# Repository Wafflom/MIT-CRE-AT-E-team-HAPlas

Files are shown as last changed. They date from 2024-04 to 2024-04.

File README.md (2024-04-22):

# MIT-CRE[AT]E-team-HAPlas
Code and CAD models repository for our MIT CRE[AT]E challenge device, a haptic and auditory feedback device.

# BOM:
### Electronics:
  - [Seeed Studio XIAO nRF52840 Sense](https://www.seeedstudio.com/Seeed-XIAO-BLE-Sense-nRF52840-p-5253.html)
  - [DFPlayer mini MP3 player](https://www.dfrobot.com/product-1121.html)
  - [1W 40mm 2 pin speaker](https://www.amazon.com/Fielect-Magnet-Speaker-Internal-Loudspeaker/dp/B083TDLGNB?th=1)
  - [UltraFire 10440 Li-ion battery](https://www.batteryupgrade.com/shopBrowser.php?assortmentProductId=21883872&shopGroupId=70741364)
  - Sacrificial USB-C Cable (it will be cut to hijack the power pins, so use one you do not need anymore)
### Hardware:
  - 4x M3x8mm Countersunk hex head screws
  - 1.5mm thick, 15mm wide double-sided foam tape
  - 26AWG wire (for the electronics)
  - 250~ grams of PLA (PLA+ recommended, color is up to preference) We used [Bambulabs PLA MATTE](https://us.store.bambulab.com/products/pla-matte-filament?variant=41078280093832)
  - 12mm Brass rod (other types of dense metal can be used depending on preference and availiability)

### Tools:
  - Soldering Iron
  - 3d Printer
  - Screwdriver
  - Lathe

# Printed Parts and settings
[STL's found here](https://github.com/Wafflom/MIT-CREATE-team-HAPlas/tree/002e4f92e56438b101ec2bbca2ead18dcc9f6623/STL's)
## Main Body STL
#### QTY: 1
### Suggested Print Settings:
  - 0.16mm Layer Height
  - 3 Walls
  - 6 Top & Bottom layers
  - 20% Infill
  - Cubic infill pattern
  - Supports on (tree supports suggested)

#### Orientation in slicer (Orca slicer shown)

#### Sliced with Supports (Orca slicer shown)


## Electronics Bay Cap STL
#### QTY: 1
### Suggested Print Settings:
  - 0.2mm Layer Height
  - 3 Walls
  - 100% Infill
  - Supports off

#### Orientation in slicer (Orca slicer shown)

#### Sliced No Supports


## Cap STL
#### QTY: 2
### Suggested Print Settings:
  - 0.16mm Layer Height
  - 3 Walls
  - 4 Top & Bottom layers
  - 40% infill
  - Cubic infill pattern
  - Supports off

#### Orientation in slicer (Orca slicer shown)

#### Sliced No Supports (Orca slicer shown)


## Battery Holder STL
#### QTY: 1
### Suggested Print Settings:
  - 0.16mm Layer Height
  - 3 Walls
  - 100% Infill
  - Supports on (tree supports suggested)

#### Orientation in slicer (Orca slicer shown)

#### Sliced with Supports (Orca slicer shown)


# Code upload instructions
## Install the Arduino IDE 
  - [Download link](https://www.arduino.cc/en/software)
## Install the Seeed Studio board library
  - After opening the Arduino IDE click on File > Preference, and fill in Additional Boards Manager URLs with the URL below:
    https://files.seeedstudio.com/arduino/package_seeeduino_boards_index.json

## Select which program variant you want to use
  - [click here for code options](https://github.com/Wafflom/MIT-CREATE-team-HAPlas/tree/86a4da8f8bbf2c63ec49366ca752f0183104cafe/Code)
## Select the board in Arduino programmer and hit upload


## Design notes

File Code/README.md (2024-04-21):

# Code used for audio playback
Two different variants of the program have been provided. The first, `Code_Simple.ino` is a simple one that activates the audio upon exceeding an acceleration threshold (measured in m/s^2) that can be used by users desiring a more simple device that always activates sound on the action. The second program, `Code_Gesture_detection.ino`, the one used in our final product and testing footage, utilizes a gesture recognition machine learning model made using edge impulse. This option allows users to correspond specific sounds to specific actions that can be made; we have provided the one we used for our final iteration if you would like to try it out without having to create your own model. ``Note that this model was calibrated for the movements of a 5-year-old and may not function well for an adult.``
# Using Gesture recognition:
### If the usage of gesture recognition is desired, you can either use the included gesture library:
  - [Gesture Library](https://github.com/Wafflom/MIT-CRE-AT-E-team-HAPlas/tree/48943a845ded3df958085c8eb5ed810e9c71b0dc/Code/Gesture%20Library)
### Or you can create your own using these instructions provided by Seedduino:
  - [Library creation instructions](https://wiki.seeedstudio.com/XIAOEI/)
    
## Default Gestures:
  - Jab (straight punch)
  - Uppercut
  - Hook
## Library upload instructions:
  - Download the library

  - Upload to Arduino IDE

  - Include the library in the program

  **Note If using your own library, replace the file name in the quotations with your own library name
    
# File naming convention:
`*Note this is only if you want to use your own audio, if you want to use the same ones we did you can find those files here:` [Audio We Used](https://github.com/Wafflom/MIT-CREATE-team-HAPlas/tree/86a4da8f8bbf2c63ec49366ca752f0183104cafe/Code/Audio%20Files)
#### When uploading audio files to the SD card for the MP3 player, ensure that the files are in the root directory of the SD card and are named 001, 002, 003... etc. 
#### You will call to play these files using the function:
```ruby
myDFPlayer.play(/*number*/);
```
#### With the number corresponding to the file you want to be played, this convention for naming should also be used if the user desires to use different audio files than the ones we used.

# Code upload instructions
## Install the Arduino IDE 
  - [Download link](https://www.arduino.cc/en/software)
## Install the Seeed Studio board library
  - After opening the Arduino IDE click on File > Preference, and fill in Additional Boards Manager URLs with the URL below:
    https://files.seeedstudio.com/arduino/package_seeeduino_boards_index.json

## Select the board in Arduino programmer and hit upload


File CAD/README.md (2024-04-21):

# Files made in Fusion 360 on education license
### Revisions denoted by the final number in the file name, Revision 1 being first and 3 being the latest and final variant
  - .STEP and .F3d/.F3z files all provided

# BOM:
### Electronics:
  - [Seeed Studio XIAO nRF52840 Sense](https://www.seeedstudio.com/Seeed-XIAO-BLE-Sense-nRF52840-p-5253.html)
  - [DFPlayer mini MP3 player](https://www.dfrobot.com/product-1121.html)
  - [1W 40mm 2 pin speaker](https://www.amazon.com/Fielect-Magnet-Speaker-Internal-Loudspeaker/dp/B083TDLGNB?th=1)
  - [UltraFire 10440 Li-ion battery](https://www.batteryupgrade.com/shopBrowser.php?assortmentProductId=21883872&shopGroupId=70741364)
  - Sacrificial USB-C Cable (it will be cut to hijack the power pins, so use one you do not need anymore)
### Hardware:
  - 4x M3x8mm Countersunk hex head screws
  - 1.5mm thick, 15mm wide double-sided foam tape
  - 26AWG wire (for the electronics)
  - 250~ grams of PLA (PLA+ recommended, color is up to preference) We used [Bambulabs PLA MATTE](https://us.store.bambulab.com/products/pla-matte-filament?variant=41078280093832)

### Tools:
  - Soldering Iron
  - 3d Printer
  - Screwdriver

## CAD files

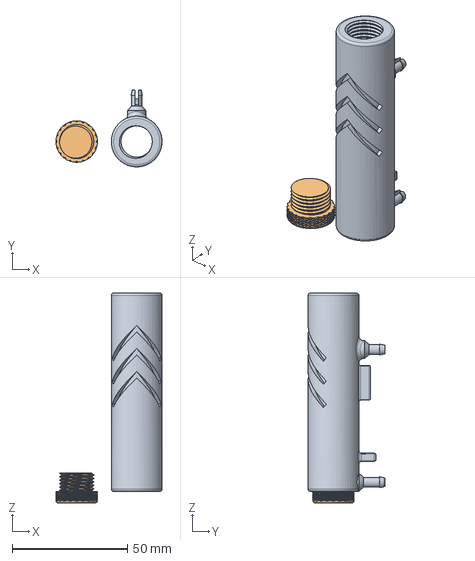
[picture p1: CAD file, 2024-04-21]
CAD/Haptic Attachment Full CAD STEP Revision 2.step
46.0 x 33.3 x 91.0 mm

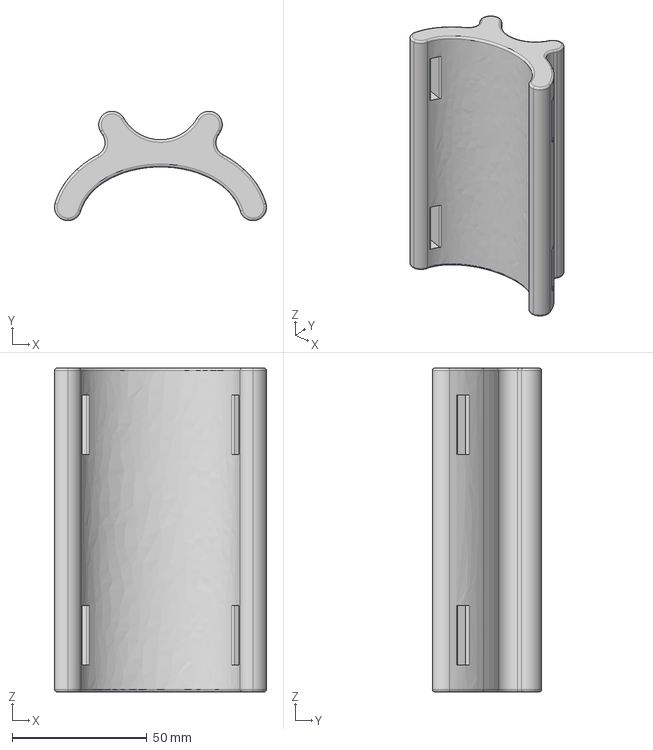
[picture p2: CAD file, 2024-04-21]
CAD/Prototype arm mount Full CAD STEP Revision 1.step
78.6 x 40.5 x 120.0 mm

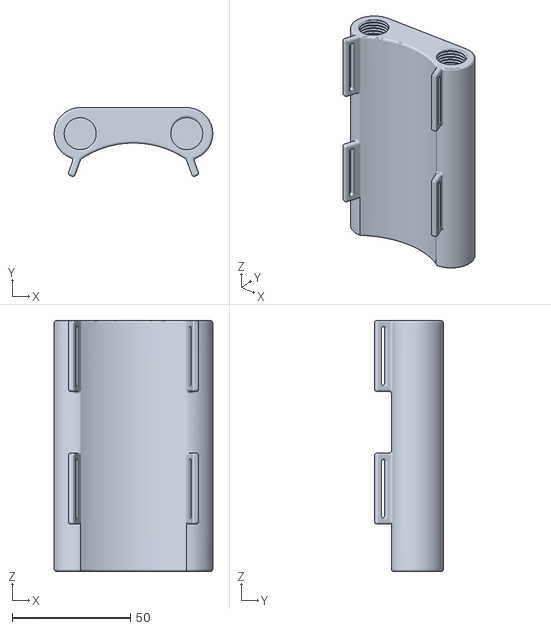
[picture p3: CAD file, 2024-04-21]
STL's/Main Body.stl
67.0 x 29.1 x 106.0

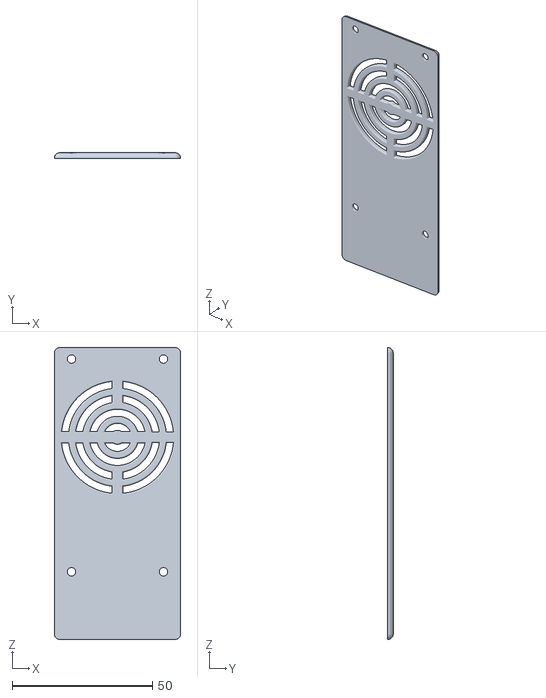
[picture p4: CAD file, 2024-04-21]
STL's/Electronics Bay Cap.stl
45.0 x 2.00 x 104.0

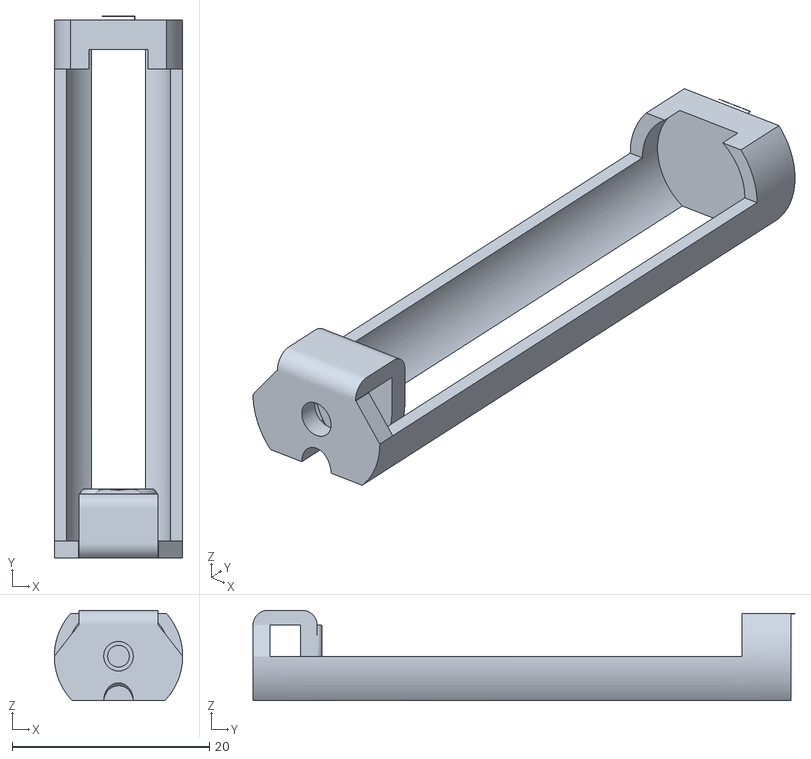
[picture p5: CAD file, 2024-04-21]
STL's/Battery Holder.stl
13.0 x 54.9 x 9.14

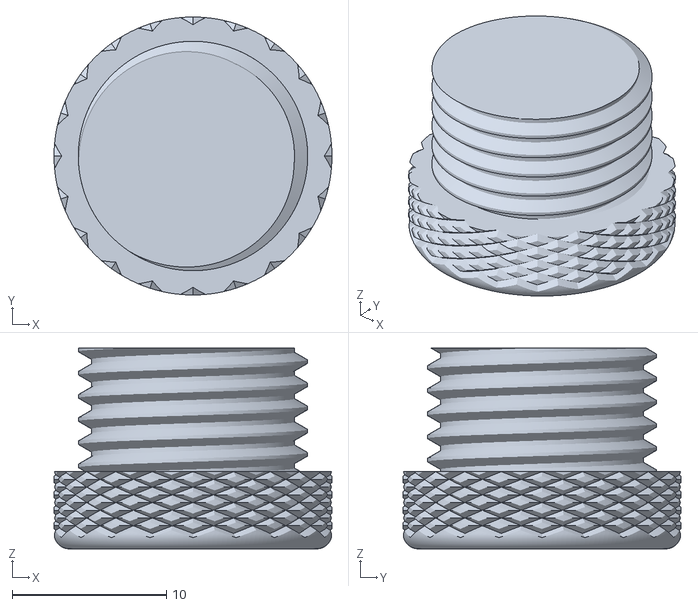
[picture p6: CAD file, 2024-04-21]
STL's/Cap.stl
18.0 x 18.0 x 13.0

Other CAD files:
CAD/Haptic Attachment Full CAD F3d Revision 2.f3d
CAD/Prototype arm mount Full CAD F3d Revision 1.f3d

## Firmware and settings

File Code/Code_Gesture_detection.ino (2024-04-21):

/* Includes ---------------------------------------------------------------- */
#include <motion_recognition_test_MIT_inferencing.h>
#include <LSM6DS3.h>
#include <Wire.h>
#include <DFRobotDFPlayerMini.h>
/* Constant defines -------------------------------------------------------- */
#define CONVERT_G_TO_MS2    9.80665f
#define MAX_ACCEPTED_RANGE  2.0f        // starting 03/2022, models are generated setting range to +-2, but this example use Arudino library which set range to +-4g. If you are using an older model, ignore this value and use 4.0f instead
/* MP3 Player Setup -------------------------------------------------------- */
DFRobotDFPlayerMini myDFPlayer;
SoftwareSerial softSerial(/*rx =*/7, /*tx =*/6);
/* Private variables ------------------------------------------------------- */
static bool debug_nn = false; // Set this to true to see e.g. features generated from the raw signal
LSM6DS3 myIMU(I2C_MODE, 0x6A);
/**
* @brief      Arduino setup function
*/
void setup()
{
    // put your setup code here, to run once:
    Serial.begin(115200);

    if (!myDFPlayer.begin(Serial)) {
      Serial.println(F("Unable to begin:"));
      Serial.println(F("1.Please recheck the connection!"));
      Serial.println(F("2.Please insert the SD card!"));
    while (true);
    }

    Serial.println(F("DFPlayer Mini online."));
    myDFPlayer.volume(30);  // Set volume level (0-30)
    Serial.println("Edge Impulse Inferencing Demo");

    if (!myIMU.begin()) {
      Serial.println("Failed to initialize IMU!\r\n");
    } else {
      Serial.println("IMU initialized\r\n");
    }

    if (EI_CLASSIFIER_RAW_SAMPLES_PER_FRAME != 3) {
      Serial.println("ERR: EI_CLASSIFIER_RAW_SAMPLES_PER_FRAME should be equal to 3 (the 3 sensor axes)\n");
      return;
    }
}

/**
 * @brief Return the sign of the number
 * 
 * @param number 
 * @return int 1 if positive (or 0) -1 if negative
 */
float ei_get_sign(float number) {
    return (number >= 0.0) ? 1.0 : -1.0;
}

/**
* @brief      Get data and run inferencing
*
* @param[in]  debug  Get debug info if true
*/
void loop()
{


    delay(2000);

    // Allocate a buffer here for the values we'll read from the IMU
    float buffer[EI_CLASSIFIER_DSP_INPUT_FRAME_SIZE] = { 0 };

    for (size_t ix = 0; ix < EI_CLASSIFIER_DSP_INPUT_FRAME_SIZE; ix += 3) {
        // Determine the next tick (and then sleep later)
        uint64_t next_tick = micros() + (EI_CLASSIFIER_INTERVAL_MS * 1000);

buffer[ix] = myIMU.readFloatAccelX();
buffer[ix+1] = myIMU.readFloatAccelY();
buffer[ix+2] = myIMU.readFloatAccelZ();


        for (int i = 0; i < 3; i++) {
            if (fabs(buffer[ix + i]) > MAX_ACCEPTED_RANGE) {
                buffer[ix + i] = ei_get_sign(buffer[ix + i]) * MAX_ACCEPTED_RANGE;
            }
        }

        buffer[ix + 0] *= CONVERT_G_TO_MS2;
        buffer[ix + 1] *= CONVERT_G_TO_MS2;
        buffer[ix + 2] *= CONVERT_G_TO_MS2;

        delayMicroseconds(next_tick - micros());
    }

    // Turn the raw buffer in a signal which we can the classify
    signal_t signal;
    int err = numpy::signal_from_buffer(buffer, EI_CLASSIFIER_DSP_INPUT_FRAME_SIZE, &signal);
    if (err != 0) {
        Serial.println("Failed to create signal from buffer (%d)\n", err);
        return;
    }

    // Run the classifier
    ei_impulse_result_t result = { 0 };

    err = run_classifier(&signal, &result, debug_nn);
    if (err != EI_IMPULSE_OK) {
        Serial.println("ERR: Failed to run classifier (%d)\n", err);
        return;
    }

#if EI_CLASSIFIER_HAS_ANOMALY == 1
    Serial.println("    anomaly score: %.3f\n", result.anomaly);
#endif

  if (result.classification[1].value > 0.5) {
      myDFPlayer.play(1);  // Play file number 1 for "FORWARD BACKWARD"
      Serial.println("Playing audio for 'FORWARD BACKWARD'");
      delay(2000);
   }
   
  if (result.classification[0].value > 0.5) {
       myDFPlayer.play(2);  // Play file number 2 for "UPPERCUT"
      Serial.println("Playing audio for 'UPPERCUT'");
      delay(2000);
   }
 
   if (result.classification[2].value > 0.5) {
      myDFPlayer.play(3);  // Play file number 3 for "HOOK"
      Serial.println("Playing audio for 'HOOK'");
          delay(2000);
   }
 
}

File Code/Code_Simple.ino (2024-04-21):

#include <Wire.h>
#include <LSM6DS3.h>
#include <DFRobotDFPlayerMini.h>
#include <SoftwareSerial.h>
SoftwareSerial softSerial(/*rx =*/7, /*tx =*/6);

#define CONVERT_G_TO_MS2    9.80665f
#define MAX_ACCEPTED_RANGE  2.0f 

// IMU
LSM6DS3 myImu(I2C_MODE, 0x6A);  // I2C address for LSM6DS3

// DFPlayer Mini setup
DFRobotDFPlayerMini myDFPlayer;  

void setup() {
  Serial.begin(115200);
  softSerial.begin(9600);
  if (!myDFPlayer.begin(softSerial)) {
    Serial.println(F("Unable to begin:"));
    Serial.println(F("1.Please recheck the connection!"));
    Serial.println(F("2.Please insert the SD card!"));
    while (true);
  }
  Serial.println(F("DFPlayer Mini online."));
  myDFPlayer.volume(20); // Set volume level (0-30)

  if (myImu.begin() != 0) {
    Serial.println("Failed to initialize the LSM6DS3 sensor.");
    while (1);
  }

  Serial.println("LSM6DS3 initialized.");
}

void loop() {
  float x, y, z;
  x = myImu.readFloatAccelX();
  y = myImu.readFloatAccelY();
  z = myImu.readFloatAccelZ();

  // Determine the axis with the greatest acceleration
  if (abs(x) > 2.5 || abs(y) > 2.5|| abs(z) > 2.5) { // Threshold to detect a punch
    Serial.println("Punch detected!");
    
    if (abs(x) > abs(y) && abs(x) > abs(z)) {
      Serial.println("Punch on X-axis");
      myDFPlayer.play(1);
      delay(250);
    } else if (abs(y) > abs(x) && abs(y) > abs(z)) {
      Serial.println("Punch on Y-axis");
      myDFPlayer.play(2);
      delay(250);
    } else {
      Serial.println("Punch on Z-axis");
      myDFPlayer.play(3);
      delay(250);
    }

    delay(500);  // Shorter delay to improve responsiveness
  }

  delay(100);
}

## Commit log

2024-04-21 Create CAD
2024-04-21 Rename Body2.stl to Electronics Bay cap.stl
    [Body2.stl, Electronics Bay cap.stl]
2024-04-21 Update and rename Electronics Bay cap.stl to STL's/Electronics Bay cap.stl
    [Electronics Bay cap.stl]
2024-04-21 Update and rename Electronics Bay cap.stl to Electronics_Bay_Cap.stl
    [Electronics_Bay_Cap.stl]
